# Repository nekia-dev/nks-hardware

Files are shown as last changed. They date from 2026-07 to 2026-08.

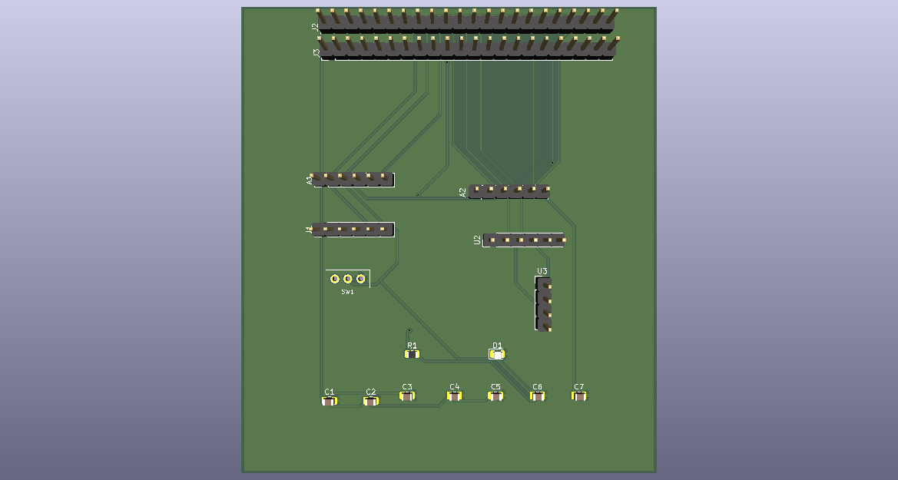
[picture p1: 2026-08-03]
nks-03-08-2026.png

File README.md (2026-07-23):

# NkS — Placa portadora (carrier) · PROYECTO SOMNIA

**Nekia Systems S.L.** · Hardware del monitor de sueño NkS
*"Your Data, Your Device."*

Placa portadora para ESP32-S3 DevKitC-1 N16R8. Diseño "árbol de pascua apagado":
hardware mínimo, el valor está en el software.

---

## Estado

| Etapa | Estado |
|---|---|
| Hardware congelado | ✅ |
| Esquemático + ERC | ✅ 0 errores |
| Layout + DRC | ✅ 0 errores / 0 sin conectar |
| Gerbers | ✅ generados y verificados |
| Fabricación | ⏳ pendiente de pedido |
| Validación física | ⏳ pendiente (ver §Validación) |

---

## Datos de fabricación

| Parámetro | Valor |
|---|---|
| Dimensiones | **80 × 90 mm** (8 × 9 cm) |
| Capas | 2 (F.Cu / B.Cu) |
| Grosor | 1,6 mm (estándar) |
| Contorno | Rectangular |
| Plano de masa | GND en **ambas** caras |
| Pistas | 271 segmentos + 4 vías |
| Taladros | 80 (brocas 0,3 / 1,0 / 1,1 mm) |
| Ancho de pista | 0,2 mm (señal) |
| Componentes | 18 |

> El formato circular queda aplazado: el rectangular abarata el prototipo.

---

## Arquitectura

El ESP32-S3 DevKitC-1 **no va soldado**: se enchufa sobre dos tiras de pines
hembra 1×22 (`J2` = fila J1 del DevKit, `J3` = fila J3). Los sensores y
periféricos son módulos comerciales (breakouts) montados sobre headers.

**Consecuencia:** el fabricante entrega la placa **desnuda**. El montaje
(soldadura de headers y pasivos + enchufar el DevKit) es manual.

---

## Pinout congelado

| Bus | Señal | GPIO | Posición en header |
|---|---|---|---|
| I2S | WS | 11 | J2 pos. 17 |
| I2S | SCK | 12 | J2 pos. 18 |
| I2S | SD | 13 | J2 pos. 19 |
| SPI | MOSI | 15 | J2 pos. 8 |
| SPI | MISO | 16 | J2 pos. 9 |
| SPI | SCLK | 17 | J2 pos. 10 |
| SPI | CS | 18 | J2 pos. 11 |
| I2C | SDA | 8 | J2 pos. 12 |
| I2C | SCL | 9 | J2 pos. 15 |
| — | Botón on/off | 14 | J2 pos. 20 |
| — | LED estado | 21 | J3 pos. 18 |

**Alimentación:** 3V3 en J2 pos. 1–2 · GND en J2 pos. 22 y J3 pos. 1, 21, 22.

**Pines reservados (no usar):** strapping 0/3/45/46 · PSRAM octal (N16R8)
33–37 · USB nativo 19/20.

> El pinout físico J1/J3 procede de la guía oficial de Espressif del
> ESP32-S3-DevKitC-1 v1.1. **Verificar contra la placa real antes de soldar**
> (ver §Validación).

---

## BOM

| Ref | Componente | Interfaz | Notas |
|---|---|---|---|
| J2, J3 | Header 1×22 hembra ×2 | — | Zócalo del DevKit (paso 2,54 mm, filas a 22,86 mm) |
| A1 | INMP441 | I2S | Canal izquierdo — `L/R` → GND |
| A2 | INMP441 | I2S | Canal derecho — `L/R` → 3V3 |
| J1 | Lector microSD | SPI | — |
| U2 | RTC DS3231 + AT24C32 | I2C | 0x68 / 0x57 |
| U3 | SHT30 | I2C | 0x44 — temperatura + humedad |
| SW1 | Pulsador 6 mm | — | On/off, activo-bajo |
| R1 | 1 kΩ (0805) | — | Serie del LED |
| R2 | 10 kΩ (0805) | — | Pull-up del botón |
| D1 | LED (0805) | — | Indicador de estado |
| C1–C6 | 100 nF (0805) | — | Desacoplo + antirrebote |
| C7 | 10 µF (0805) | — | Bulk en el riel 3V3 |

**Aparte (no van en la placa):** ESP32-S3 DevKitC-1 N16R8, tarjeta microSD,
cable USB-C, carcasa.

Todas las huellas proceden de las **librerías estándar de KiCad**; el proyecto
no depende de librerías propias de footprints.

---

## Estructura del repositorio

```
nks.kicad_pro          Proyecto KiCad
nks.kicad_sch          Esquemático
nks.kicad_pcb          Placa (rutada, DRC limpio)
nks.kicad_sym          Biblioteca de símbolos del proyecto
sym-lib-table          Registro de la biblioteca de símbolos
docs/                  Informes de ingeniería
tools/nks-sch-gen/     Generador del esquemático en Rust
```

### Abrir el proyecto

Abrir `nks.kicad_pro` con **KiCad 10.0**. Los cuatro archivos de proyecto y
`sym-lib-table` deben estar en la misma carpeta.

---

## Validación (pendiente al recibir la placa)

El DRC a cero garantiza que la placa **coincide con el esquemático** y es
fabricable. **No** garantiza que el mapeo de pines del DevKit sea correcto.

1. **Continuidad con multímetro** (placa desnuda): comprobar que cada pad de
   los módulos pita con la posición esperada de J2/J3. Prioridad: I2C, I2S, SPI.
2. **Alimentación**: 3V3 y GND presentes en cada módulo antes de montar nada.
3. **Bloque a bloque**: alimentación → I2C (¿responde el RTC en 0x68?) → I2S →
   microSD. No montar todo de golpe.

---

## Decisiones de diseño registradas

- **2× INMP441 en estéreo** por el truco `L/R`: comparten los tres pines I2S sin
  GPIO adicionales. Habilita separar el ronquido propio del de la pareja.
- **SHT30 incorporado** como sensor de ambiente (temp + humedad). Restricción de
  layout: aislarlo térmicamente del DevKit y su regulador.
- **Sin conector USB-C propio**: se usa el USB-C nativo del DevKit.
- **BMP280 descartado**; **BH1750 aplazado**.
- **Plano de GND en ambas caras**: necesario porque D1 es SMD (su pad de masa
  vive solo en F.Cu) y el plano inferior quedó fragmentado por el rutado.

---

*Nekia Systems S.L. — CONFIDENCIAL*

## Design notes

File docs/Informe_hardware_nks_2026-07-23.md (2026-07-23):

# INFORME DE INGENIERÍA — Placa NkS (carrier)
# Nekia Systems S.L. · PROYECTO SOMNIA
# Fecha: 23 de julio de 2026
# Alcance: del pinout congelado a los Gerbers verificados

---

## 1. RESUMEN EJECUTIVO

Se cierra el diseño de la placa portadora del NkS: esquemático con ERC a 0,
layout con DRC a 0 errores y 0 conexiones sin rutar, y Gerbers generados y
verificados capa por capa. Placa de **80 × 90 mm, 2 capas**, con plano de masa
en ambas caras.

En paralelo se reorientó el producto (de dispositivo médico a producto de
consumo con la privacidad como bandera), se añadió el SHT30 como sensor de
ambiente y se pasó a **captura estéreo con dos INMP441**.

Queda pendiente lo único que el DRC no puede validar: **el mapeo de pines del
DevKit contra la placa física**.

---

## 2. DECISIONES DE PRODUCTO Y HARDWARE

### 2.1 Segundo micrófono (estéreo)

Se añade un segundo INMP441 aprovechando el pin `L/R` del integrado: un módulo
con `L/R`→GND (canal izquierdo) y otro con `L/R`→3V3 (canal derecho). Ambos
comparten `WS`/`SCK`/`SD`.

**Coste real:** cero GPIO adicionales y coherencia de fase gratuita (comparten
reloj). El trabajo se traslada al software: I2S a 2 canales, formato `.nka` con
dos canales (dobla almacenamiento) y colocación intencional de A1/A2 en el
layout (define el *baseline* estéreo).

**Descartado:** matrices de 4+ micrófonos. El INMP441 no soporta TDM
multicanal; un array mayor exigiría otro sensor y otro diseño.

### 2.2 SHT30 (temperatura + humedad)

Entra al bus I2C existente (0x44) sin GPIO nuevos. Se acepta como **feature de
producto** ("ambiente del dormitorio"), no como dato suelto: el DS3231 ya ofrece
temperatura aproximada, pero mide su propio die y no sirve como medida ambiental.

**Restricción de layout:** aislar del DevKit y su regulador; de lo contrario
reporta temperatura alta y humedad baja.

### 2.3 Sin conector USB-C propio

El DevKitC-1 ya expone el USB-C nativo del ESP32-S3 (vía para el futuro USB Mass
Storage). Se elimina el bloque de conector independiente.

### 2.4 Contorno rectangular

Se aplaza el formato circular: el rectangular abarata el prototipo y el contorno
no aporta valor hasta validar la electrónica.

---

## 3. FLUJO DE TRABAJO ADOPTADO

El esquemático se generó **programáticamente con una herramienta propia en
Rust** (`tools/nks-sch-gen`), que emite `.kicad_sch`, `.kicad_sym` y
`sym-lib-table`. El usuario ejecuta, revisa y ajusta en KiCad 10.

**Justificación:** reproducibilidad y control de versiones del esquemático; se
evita Python por decisión de toolchain del proyecto.

**Limitación asumida:** un esquemático generado queda correcto en conectividad
(net labels) pero no en estética. La reorganización visual, si se quiere, es
manual.

---

## 4. INCIDENCIAS RESUELTAS (y su causa raíz)

### 4.1 Formato `.kicad_sch` rechazado por KiCad

**Causa:** los sub-símbolos anidados se emitían con el prefijo de biblioteca
(`nks:R1_0_1`). KiCad exige el nombre sin prefijo (`R1_0_1`).

### 4.2 Referencias marcadas como "sin anotar"

**Causa:** las instancias apuntaban a la ruta `/` en lugar de a la UUID de la
hoja raíz. Corregido en el generador.

**Relacionado:** referencias tipo `J1H`/`J3H` son inválidas en KiCad (deben
terminar en número). Renombradas a `J2`/`J3`.

### 4.3 "No se ha encontrado la huella 'nks:ESP32-S3-DevKitC-1'"

**Causa:** se creó un footprint a medida en una biblioteca de proyecto
(`nks.pretty` + `fp-lib-table`) que KiCad no cargaba de forma fiable.

**Solución adoptada:** eliminar la biblioteca propia y representar el DevKit
como **dos conectores 1×22 estándar** (`J2`, `J3`) con huellas de la librería
oficial. Cada pin lleva el número de su **posición física** en los headers J1/J3
del DevKitC-1 v1.1.

> **Regla aprendida:** evitar bibliotecas de footprints propias mientras existan
> huellas estándar equivalentes.

### 4.4 90 infracciones de margen en el layout

**Causa:** se había colocado un plano de +3V3 en `F.Cu`, la misma cara por la
que se rutaban las señales. Plano y pistas competían por el mismo espacio.

**Solución:** eliminar el plano de 3V3; el 3V3 pasa a pistas. `F.Cu` queda para
señales.

> **Regla aprendida:** un plano ocupa la cara entera; no se comparte cara entre
> plano y rutado manual denso.

### 4.5 Rutado manual bloqueado

Con las señales en una sola cara, el router interactivo dejaba de encontrar
camino (SD_CS, SD_MISO, SD_SCLK, LED_STAT, +3V3). No era un error de diseño:
falta de espacio.

**Solución:** autorouter externo (**Freerouting**), que usa ambas caras y coloca
vías. Resultado: 42 nets sin rutar → **0**, en 1,27 s.

**Nota operativa:** el GUI de Freerouting v2.2.4 falla
(`parent_iconified ... null`). Se usó en modo terminal:

```
./freerouting -de nks.dsn -do nks.ses
```

### 4.6 KiCad se cerraba al importar el `.ses`

**Causa:** el footprint del pulsador tiene pads con número duplicado (`1`,`1`,
`2`,`2`). Freerouting los desambigua como `SW1-1@1`; el importador Specctra de
KiCad no interpreta esa sintaxis y aborta con *"No se ha encontrado la
referencia 'SW1'"*.

**Solución adoptada:** convertir el rutado del `.ses` (271 segmentos + 4 vías) e
insertarlo directamente en el `.kicad_pcb`, evitando el importador. Transformada
de coordenadas verificada contra tres componentes (unidades/10000 = mm, Y
invertida).

### 4.7 Pads de GND sin conectar al plano

Persistían pads de masa sueltos (A1, A2, U2, U3, D1) pese a existir plano en
`B.Cu`.

**Causa raíz:** `D1` es **SMD** — su pad de masa vive solo en `F.Cu` y no puede
alcanzar un plano situado en la cara opuesta. Además, el plano inferior había
quedado **fragmentado** por las pistas que el autorouter trazó en `B.Cu`,
aislando pads pasantes en islas.

**Solución:** añadir una **segunda zona de GND en `F.Cu`**. Con masa en ambas
caras, todo pad —SMD o pasante— encuentra cobre de masa en su propia cara.
Resultado: `unconnected_items` → **0**.

> **Regla aprendida:** con componentes SMD, el plano de masa debe existir en la
> cara donde viven sus pads.

### 4.8 Avisos `starved_thermal`

Tres pads (A1, A2, U3) conectaban al plano con 1 radio de alivio térmico frente
a los 2 exigidos por defecto.

**Solución:** *Ajustes de la placa → Requerimientos → Cantidad mínima de radios
de alivio térmico* = **1**. Los pads estaban conectados; era una exigencia
cosmética.

### 4.9 Incidencia: borrado global excesivo

Un `Editar → Borrado global` para limpiar pistas de GND eliminó buena parte del
rutado (35 nets sin rutar). Se recuperó desde una copia previa del archivo
rutado. **Precaución:** no usar borrado global sin copia de seguridad previa.

---

## 5. VERIFICACIÓN DE GERBERS

Pack analizado archivo por archivo:

| Capa | Estado |
|---|---|
| `F_Cu` | ✅ 4727 trazos |
| `B_Cu` | ✅ 4056 trazos |
| `F_Mask` / `B_Mask` | ✅ |
| `F_Silkscreen` / `B_Silkscreen` | ✅ |
| `Edge_Cuts` | ✅ rectángulo cerrado 80 × 90 mm |
| `PTH.drl` | ✅ 80 agujeros (brocas 0,3 / 1,0 / 1,1 mm) |
| `.gbrjob` | ✅ todas las capas declaradas |

**Recuento cruzado de taladros:** 44 (J2+J3) + 18 (A1, A2, J1) + 10 (U2, U3) +
4 (SW1) + 4 (vías) = **80**. Coincide.

**Conclusión:** pack completo y coherente, apto para fabricación.

---

## 6. PENDIENTES

### Crítico (antes de soldar)
1. **Verificar el mapeo de pines del DevKit con multímetro.** Es el único
   eslabón no validado: el footprint se construyó desde la documentación
   oficial, y ni el DRC ni los Gerbers pueden detectar un error ahí.

### Fabricación
2. Pedir la placa (JLCPCB / PCBWay) y trasladar el **precio real** al modelo de
   costes `NkS_costes.xlsx` (celda de fabricación de placa).
3. Cotizar componentes y carcasa — entregable de costes: **última semana de
   agosto de 2026**.

### Hardware por confirmar
4. **Pull-ups de I2C**: se asumen presentes en los breakouts de RTC y SHT30.
   Verificar; si ninguno los trae, añadir un par de 4,7 kΩ.
5. **Orden pin↔pad** de los headers de módulo frente a los breakouts reales.

### Mejoras aplazadas
6. Ensanchar las pistas de `+3V3` (actualmente 0,2 mm por defecto del
   autorouter). Suficiente para el consumo actual, mejorable.
7. Formato circular y reducción de tamaño (hay margen sobrado en 80 × 90 mm).
8. Modelos 3D de los módulos, para validar volumen frente a la futura carcasa.

### Software (rama aparte)
9. Refactor a `single-idf`: partir del firmware actual y retirar lo que ya no
   monta la placa (BH1750, BMP280, OLED), pasar el I2S a 2 canales y versionar
   el formato `.nka` para audio estéreo + temperatura/humedad.

---

## 7. NOTAS DE MÉTODO

- **El DRC valida coherencia, no corrección.** Comprueba que la placa cumple las
  reglas y coincide con el esquemático; no que el esquemático sea correcto.
- **Distinguir conexión lógica de conexión física.** Las líneas finas
  (*ratsnest*) expresan intención; solo el cobre conecta. El contador "sin
  rutar" es el indicador fiable, no el DRC filtrado por severidad.
- **En una placa de 2 caras:** masa por plano, señales por pista. Los pads de
  masa bajan al plano con vías; no se rutea GND con pistas.
- **Copia de seguridad antes de operaciones masivas** (borrado global, importes
  de sesión, cambios de zona).

---

*Nekia Systems S.L. — CONFIDENCIAL*
*"Your Data, Your Device." 🌙*

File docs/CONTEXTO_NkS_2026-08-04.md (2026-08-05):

# INFORME DE INGENIERÍA / CONTEXTO — NkS
# Nekia Systems S.L. · Ivan (nekia-dev)
# Fecha de cierre: 4 de agosto de 2026
# Alcance: generador Rust del esquematico recreado + refactorizado (Capa 1: SW1->SPDT,
#          quitar R2). Decisiones: SHT30 se mantiene, distribucion fisica, estrategia.
# Destino: sesion siguiente (decidir sincronizacion sch<->pcb; Capas 2-3: ENABLE, TPS22918)

---

## 0. CÓMO TRABAJAMOS
- Español, "nosotros", instrucciones cortas con el porque. Medir antes de teorizar, un
  cambio verificable a la vez, copia de seguridad antes de operaciones de riesgo.
- **NUEVO ENFOQUE DE TRABAJO (definido hoy, valido a futuro):** el **generador en Rust
  (`nks-sch-gen`) es la FUENTE DE VERDAD del esquematico**. Los cambios de diseño se hacen
  en el generador (main.rs), se regenera el `.kicad_sch`, y el LAYOUT (PCB) lo ajusta Ivan
  a mano en KiCad 10. El agente ayuda a escribir/modificar el codigo Rust; Ivan compila y
  ejecuta en su maquina (`ltc`). "Rust si, Python no" (NO usar kiutils; el generador es Rust).

---

## 1. DECISIÓN ESTRATÉGICA DE FONDO (importante)
- **Reducir la dependencia del asistente.** El conocimiento del proyecto debe vivir en
  DOCUMENTACION y PROCEDIMIENTOS reproducibles, no en el asistente (que NO persiste entre
  sesiones; cada sesion es una instancia nueva que solo sabe lo que se le trae en contexto)
  ni solo en Ivan (una sola persona). Riesgo identificado por Ivan: "si no estas, el negocio
  es una ruina".
- **Plan:** cerrar la placa -> fase de documentacion/procedimientos del sistema NkS.
  Objetivo: negocio transferible, defendible ante inversor, y base para la linea de formacion
  (electronica embebida + Rust). La documentacion debe hacer a Ivan AUTONOMO, no perpetuar
  la dependencia.
- **SUBVENCION APROBADA: 7.500 EUR — pago octubre 2026.** Condiciona calendario (alta de
  autonomo, forma juridica societario vs individual, compras, ROI/IVA).

---

## 2. HITO DE HOY — generador Rust recreado + Capa 1 refactorizada

### Contexto: DOS lineas de trabajo desincronizadas (detectado y en via de resolucion)
- Una instancia ANTERIOR construyo un generador de esquematico en Rust (`nks-sch-gen`) que
  produce el `.kicad_sch` por codigo. Pero ese generador reflejaba el diseño VIEJO (SW1
  pulsador, R2 presente) — NO incorporaba el trabajo hecho a mano en las sesiones recientes.
- Esta sesion (y las previas): se edito el `.kicad_pcb` a MANO (SW1->SPDT, R2 borrado,
  rutado, DRC 0). -> Las dos lineas divergian. Hoy se empieza a consolidar en el generador.

### Recreado el proyecto Cargo
- Ubicacion: **`~/Documentos/NEKIA-SYSTEM/nks-hardware/tools/nks-sch-gen/`** (dentro del repo,
  versionado con el diseño). Ficheros: `src/main.rs` (declaracion de bloques) + `src/kicad.rs`
  (motor que escribe el `.kicad_sch`, 485 lineas, solo std). `cargo build` OK.
- NOTA: el proyecto original no estaba en la maquina de Ivan (lo construyo la otra instancia
  en su entorno); Ivan solo tenia los ficheros sueltos en `refactoriza/`. Se recreo el Cargo.
- Aviso rust-analyzer "failed to find any projects in nks-hardware": INOFENSIVO — el editor
  busca Cargo.toml en la raiz del repo, pero esta en tools/nks-sch-gen/. Solucion opcional:
  `.vscode/settings.json` con `"rust-analyzer.linkedProjects":["tools/nks-sch-gen/Cargo.toml"]`.

### Capa 1 aplicada en main.rs (SINCRONIZA generador con la realidad) — VERIFICADA
1. Constante footprint: `const SW_SPDT: &str = "nks:SS12D00";` (antes BTN6MM del pulsador).
2. `R2` (pull-up 10k) ELIMINADO.
3. `SW1` -> SPDT 3 pines: `pin 2 (comun)->BTN`, `pin 1->+3V3`, `pin 3->GND`. Footprint
   `nks:SS12D00`. Value "SW_SPDT".
- `cargo run --release` OK -> genero `nks.kicad_sch` (52409 bytes) en tools/nks-sch-gen/
  (ruta relativa; NO piso el .kicad_sch de la raiz — a proposito).
- **Verificacion (grep sobre el generado):** R2=0 ✓; SS12D00 presente ✓; **17 componentes**
  (antes 18) ✓; SW1 con nets +3V3/BTN/GND (uno de cada) ✓. Capa 1 CERRADA.

---

## 3. DECISIÓN PENDIENTE CLAVE — sincronizacion sch<->pcb (NO resuelta, para mañana)
El `.kicad_sch` generado esta limpio, PERO no se puede volcar sin mas al proyecto:
- El PCB de la raiz ya tiene el LAYOUT trabajado a mano (rutado, DRC 0), con los UUID de
  componentes del esquematico VIEJO.
- El generador crea UUID NUEVOS -> si se reemplaza el .sch y se hace *Update PCB from
  Schematic*, KiCad veria todos los componentes como nuevos -> borraria el layout/rutado
  existente. Riesgo de perder el trabajo manual del PCB.

**Opciones (decidir con mente lucida):**
- **A) El generador manda -> rehacer el layout desde cero.** Coherente con el nuevo enfoque.
  Como la reorganizacion que viene (USB-C detras, panel frontal, +TPS22918/ENABLE) va a
  rehacer el layout DE TODOS MODOS, la perdida del rutado actual es asumible. RECOMENDADA.
- **B) Mantener el PCB actual a mano; el generador queda de referencia.** Conserva el rutado
  pero perpetua la divergencia.

Si se va por A: meter tambien Capas 2-3 (ENABLE, TPS22918) en el generador ANTES de
reconstruir el layout UNA sola vez (no reconstruir dos veces).

---

## 4. REFACTORIZACIÓN PENDIENTE DEL GENERADOR (Capas 2-3)
- **Capa 2:** añadir `ENABLE` -> sacar `GPIO4` (J2 pos.4, libre, RTC-capable, validado) a un
  net ENABLE en el header J2.
- **Capa 3:** añadir `TPS22918` (load switch, parte +3V3 en +3V3_IN/+3V3_SW, EN=ENABLE) +
  divisor VBUS->ADC (5Vin en J2 pos.21; ADC libre GPIO5/6/7) + posible bulk mayor.
  Requiere definir pines del TPS22918 y valores del divisor.
- Nota: C6 (100n) sigue conectado a BTN/GND (antirrebote) — inofensivo con el SPDT, se deja.

---

## 5. DECISIONES DE PRODUCTO DE HOY
- **SHT30 (U3): SE MANTIENE.** Se valoro quitarlo por coste (ajustados), pero: (a) es un
  diferenciador de producto (ambiente del dormitorio = dato clinico/venta); (b) ya esta
  integrado; (c) ahorro modesto (~2-4 EUR). Opcion elegante disponible si hiciera falta:
  dejar el socket y hacer el MODULO opcional (el firmware detecta si responde en I2C 0x44).
  Por ahora se queda como esta.
- **Distribucion fisica de la placa (requisito de LAYOUT, no de esquematico):**
  - Borde FRONTAL: **LED (D1) + interruptor SS12D00G (SW1)** — interaccion del usuario.
  - Borde POSTERIOR: **USB-C del DevKit ("cola")** — alimentacion oculta, no cruza por
    delante. Implica ORIENTAR el DevKit sobre J2/J3 para que su USB-C nativo caiga detras.
  - Esto NO afecta al generador (el esquematico no sabe de frontal/posterior); se aplica al
    colocar componentes en el PCB.

---

## 6. ESTADO GLOBAL
- **Firmware `single-idf`:** terminado para la fase (soft power latch integrado y validado,
  commiteado). USB Mass Storage (ST-023) imprescindible (habilita "caja con USB-C").
- **Placa:** interruptor cerrado en el PCB actual (DRC 0, commiteado). Generador Rust
  sincronizado (Capa 1). Pendiente: decidir estrategia sch<->pcb + Capas 2-3 + reorganizar
  layout (USB-C detras) + regenerar Gerbers.
- **Costes:** curva PCB real (Saving: ~1.95/ud a 100u); BOM en CSV entregado. Los dos
  presupuestos base los construye Ivan (entregable ultima semana agosto, accionista).
- **Carcasa:** referencia visual validada (box router, rejilla, patas, panel USB-C detras +
  LED/switch delante). Cotas reales ~9x9.5cm; alto por confirmar con modelo 3D. Punto abierto:
  mecanica del actuador del switch (SS12D00G sin pestañas -> carro en carcasa o SS12F15).
- **Alimentacion:** por USB-C (regulador del DevKit -> 3V3). Divisor VBUS vigila los 5V.
  Pendiente decidir si la caja incluye cargador USB (recomendado, ~3-5 EUR).
- **Prioritario no-firmware:** rotar credenciales del historial git (`9991c9e`, `d751b87`).
  SIGUE PENDIENTE.

---

## 7. TEMAS ABIERTOS
- Estrategia de sincronizacion sch<->pcb (A vs B) — PRIMERA decision de mañana.
- Mecanica del actuador del switch — con la carcasa.
- Modelos 3D de modulos -> alto real de carcasa.
- Mapeo pines DevKit<->placa sin validar con multimetro (critico antes de soldar).
- Forma juridica + ROI/IVA — pendiente de la subvencion (oct 2026).
- Documentar donde vive y como se ejecuta el generador (hecho parcialmente en este informe:
  tools/nks-sch-gen/, `cargo run --release` genera el .kicad_sch en ese directorio).

---

## 8. SIGUIENTE SESIÓN — arranque
1. Decidir estrategia sch<->pcb (recomendada A: generador manda, rehacer layout).
2. Si A: meter Capa 2 (ENABLE) y Capa 3 (TPS22918 + divisor) en el generador.
3. Regenerar, validar (ERC en KiCad 10), y reconstruir el layout UNA vez con la
   distribucion nueva (USB-C detras, LED+switch delante).
4. Regenerar Gerbers -> precio PCB final.

---

*Nekia Systems S.L. — CONFIDENCIAL · "Your Data, Your Device." 🌙*

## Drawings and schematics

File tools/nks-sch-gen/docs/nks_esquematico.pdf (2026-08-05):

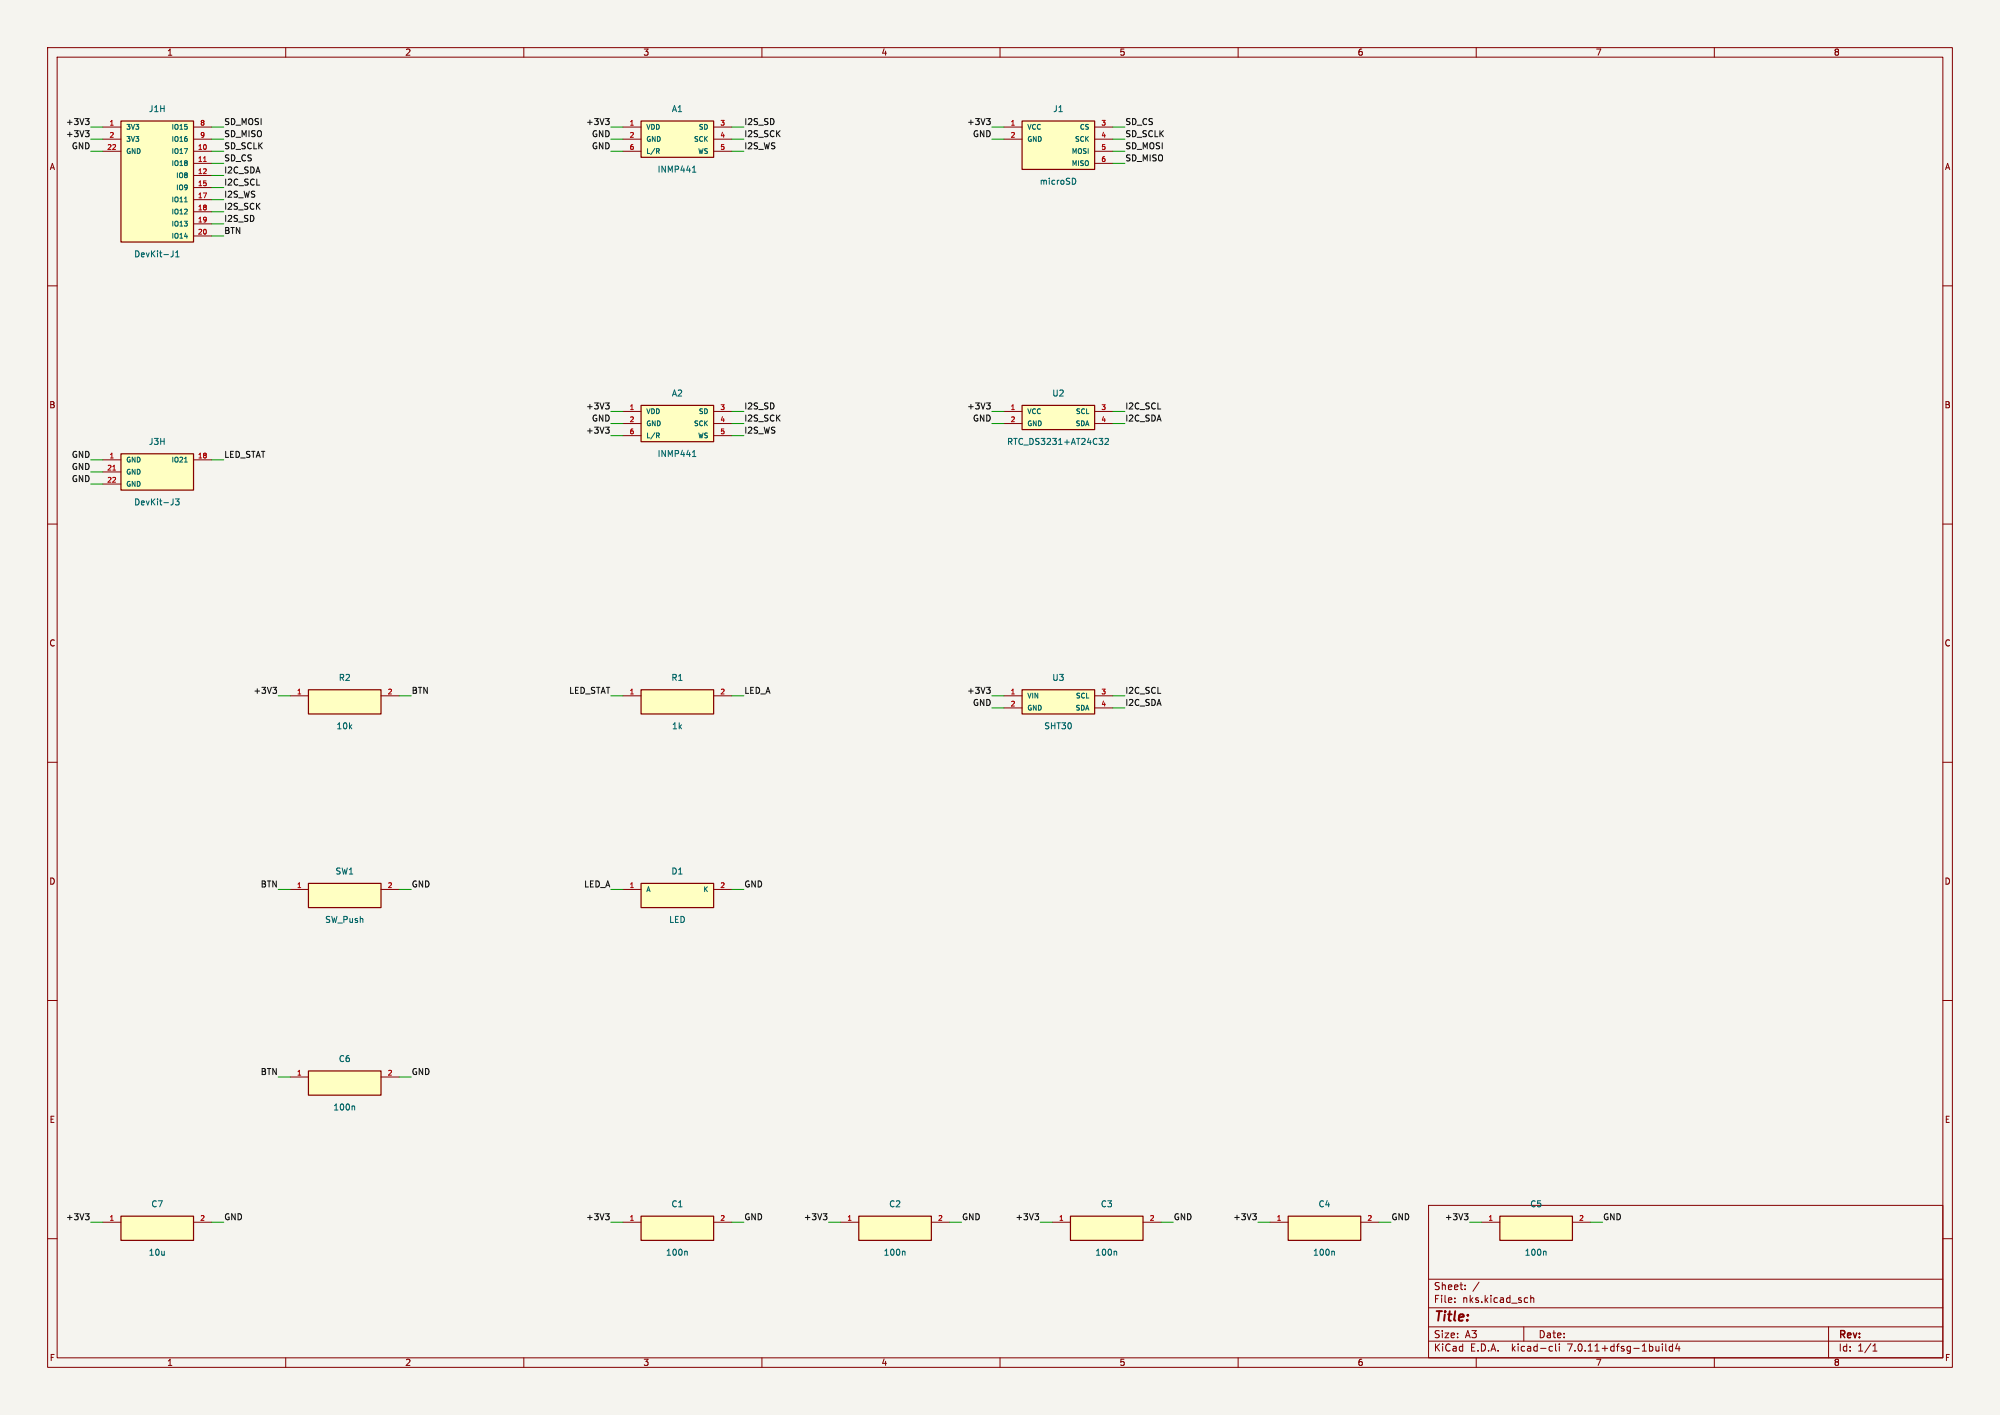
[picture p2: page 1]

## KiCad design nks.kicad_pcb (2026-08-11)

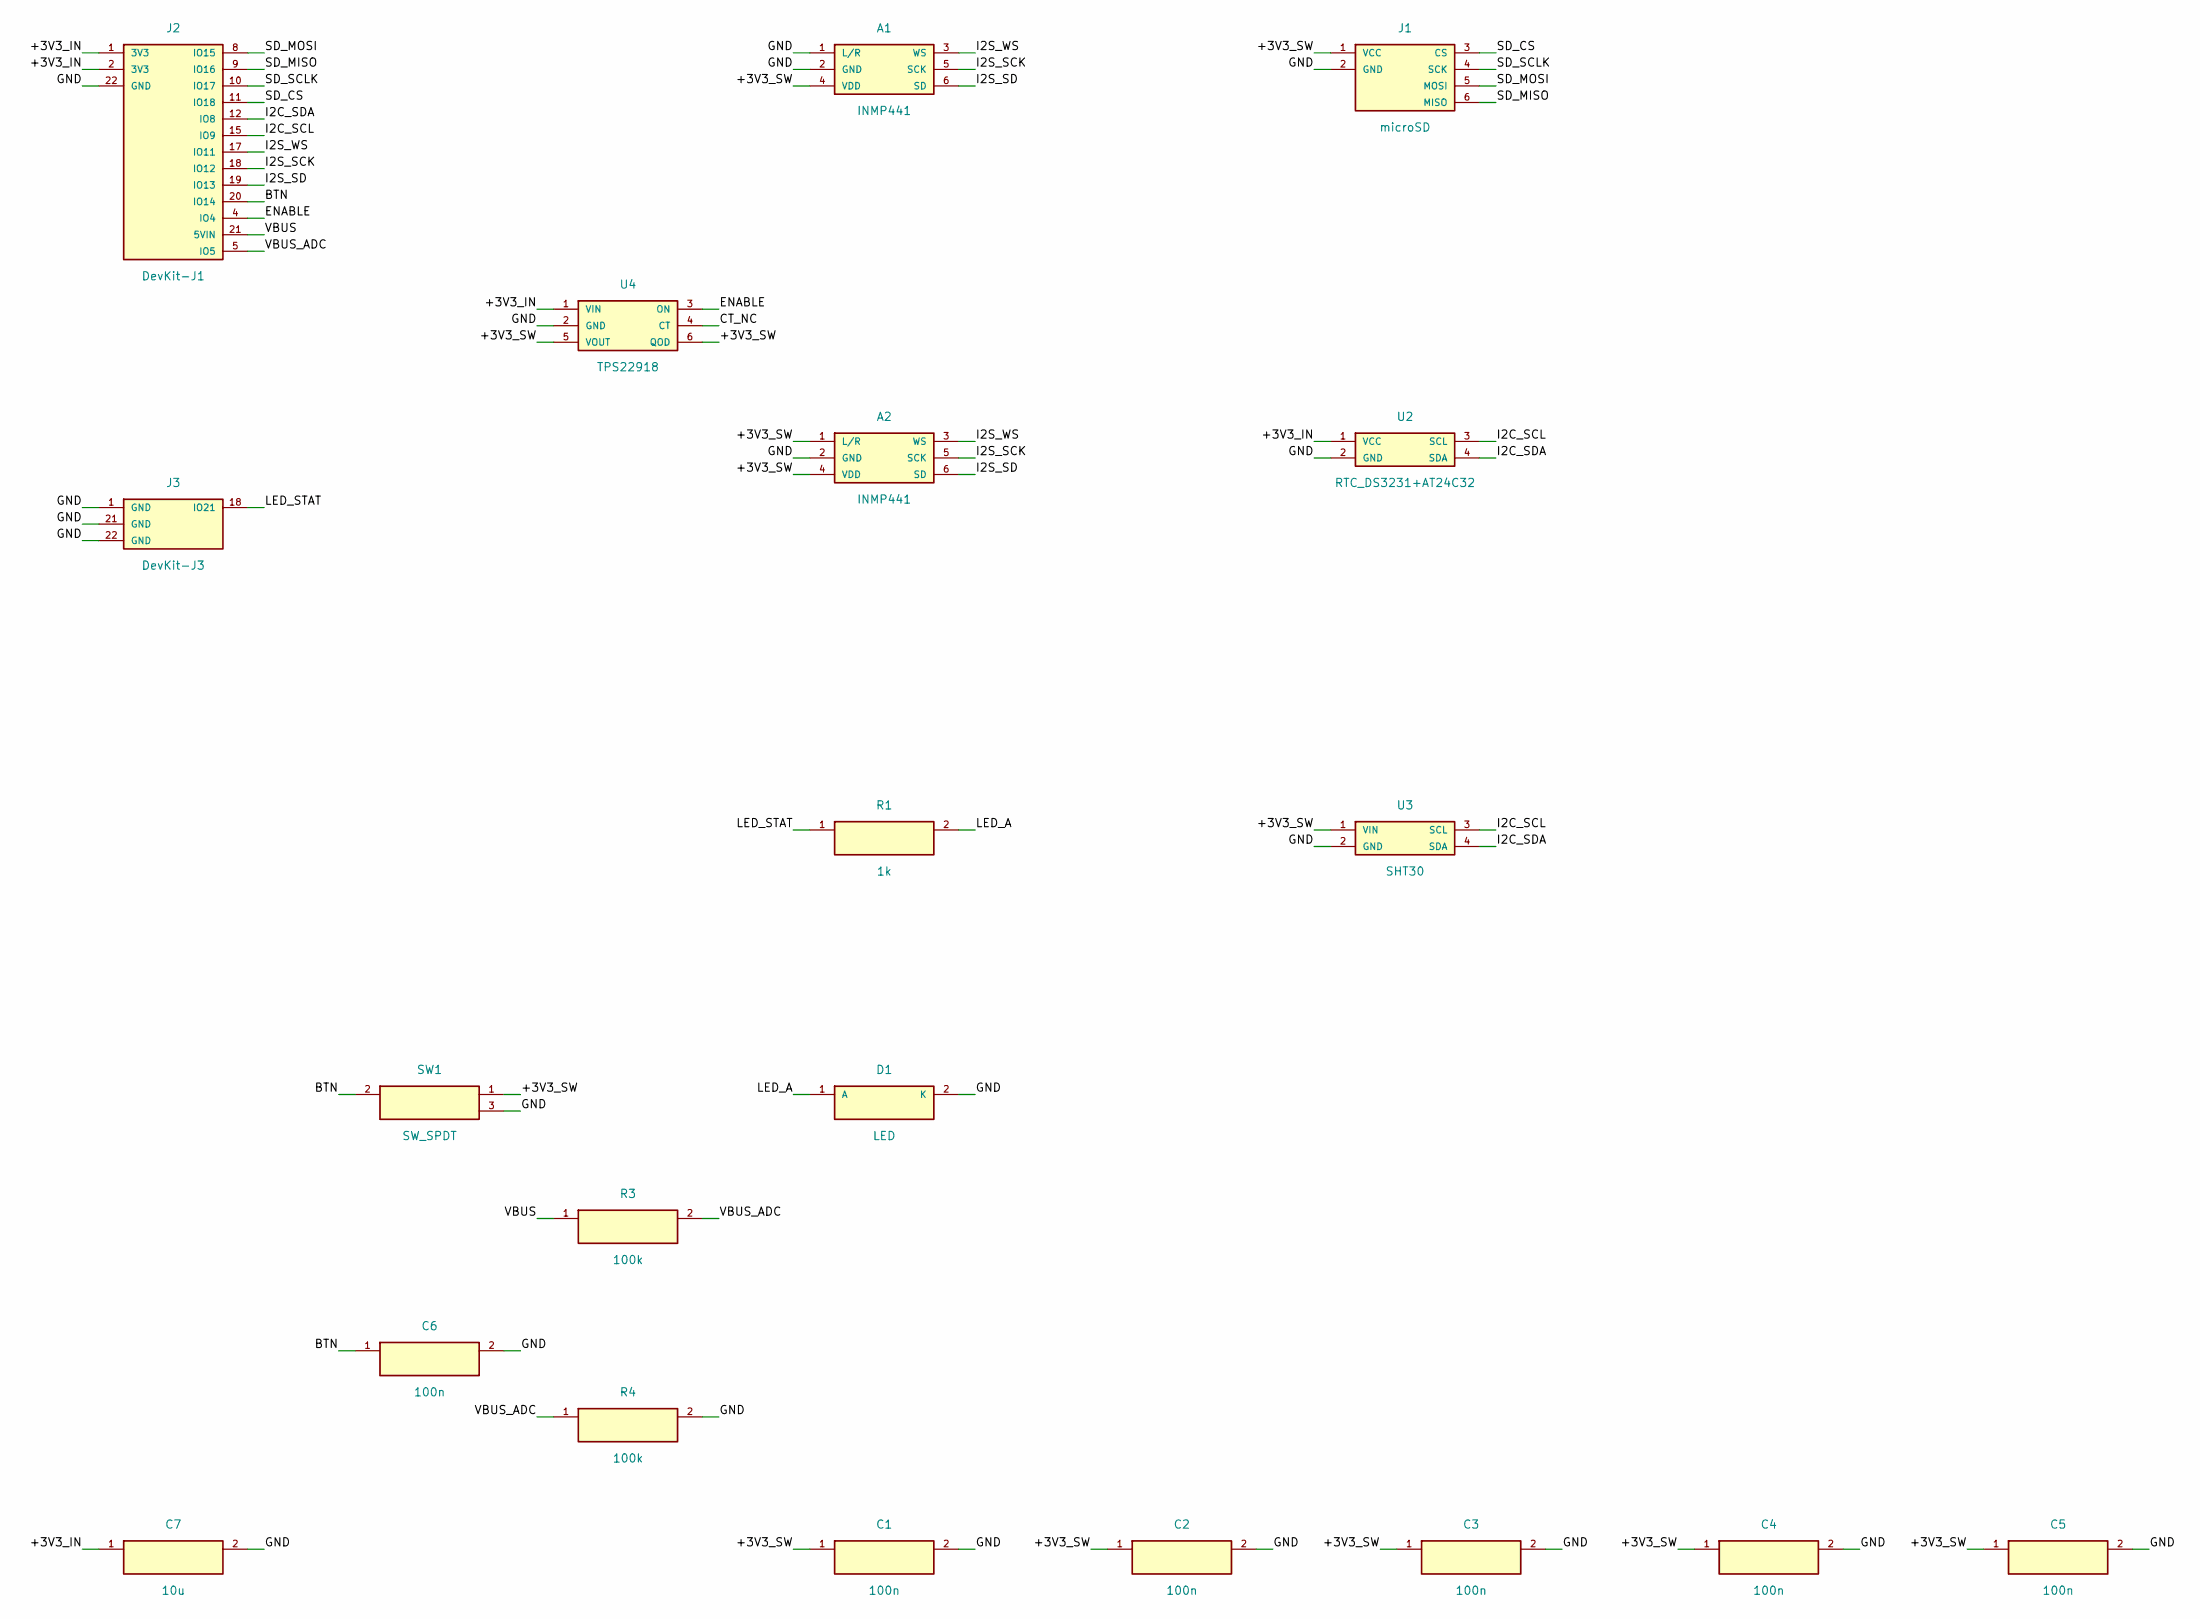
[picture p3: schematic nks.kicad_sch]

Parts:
A1, A2: INMP441; PinHeader_2x03_P2.54mm_Vertical
C1, C2, C3, C4, C5, C6: 100n; C_0805_2012Metric
C7: 10u; C_0805_2012Metric
D1: LED; LED_0805_2012Metric
J1: microSD; PinHeader_1x06_P2.54mm_Vertical
J2: DevKit-J1; PinHeader_1x22_P2.54mm_Vertical
J3: DevKit-J3; PinHeader_1x22_P2.54mm_Vertical
R1: 1k; R_0805_2012Metric
R3, R4: 100k; R_0805_2012Metric
SW1: SW_SPDT; SS12D00
U2: RTC_DS3231+AT24C32; PinHeader_1x06_P2.54mm_Vertical
U3: SHT30; PinHeader_1x04_P2.54mm_Vertical
U4: TPS22918; SOT-23-6

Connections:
/+3V3_IN: C7.1, J2.1 (3V3), J2.2 (3V3), U2.1 (VCC), U4.1 (VIN)
/+3V3_SW: A1.4 (VDD), A2.1 (L/R), A2.4 (VDD), C1.1, C2.1, C3.1, C4.1, C5.1, J1.1 (VCC), SW1.1, U3.1 (VIN), U4.5 (VOUT), U4.6 (QOD)
/BTN: C6.1, J2.20 (IO14), SW1.2
/CT_NC: U4.4 (CT)
/ENABLE: J2.4 (IO4), U4.3 (ON)
/GND: A1.1 (L/R), A1.2 (GND), A2.2 (GND), C1.2, C2.2, C3.2, C4.2, C5.2, C6.2, C7.2, D1.2 (K), J1.2 (GND), J2.22 (GND), J3.1 (GND), J3.21 (GND), J3.22 (GND), R4.2, SW1.3, U2.2 (GND), U3.2 (GND), U4.2 (GND)
/I2C_SCL: J2.15 (IO9), U2.3 (SCL), U3.3 (SCL)
/I2C_SDA: J2.12 (IO8), U2.4 (SDA), U3.4 (SDA)
/I2S_SCK: A1.5 (SCK), A2.5 (SCK), J2.18 (IO12)
/I2S_SD: A1.6 (SD), A2.6 (SD), J2.19 (IO13)
/I2S_WS: A1.3 (WS), A2.3 (WS), J2.17 (IO11)
/LED_A: D1.1 (A), R1.2
/LED_STAT: J3.18 (IO21), R1.1
/SD_CS: J1.3 (CS), J2.11 (IO18)
/SD_MISO: J1.6 (MISO), J2.9 (IO16)
/SD_MOSI: J1.5 (MOSI), J2.8 (IO15)
/SD_SCLK: J1.4 (SCK), J2.10 (IO17)
/VBUS: J2.21 (5VIN), R3.1
/VBUS_ADC: J2.5 (IO5), R3.2, R4.1

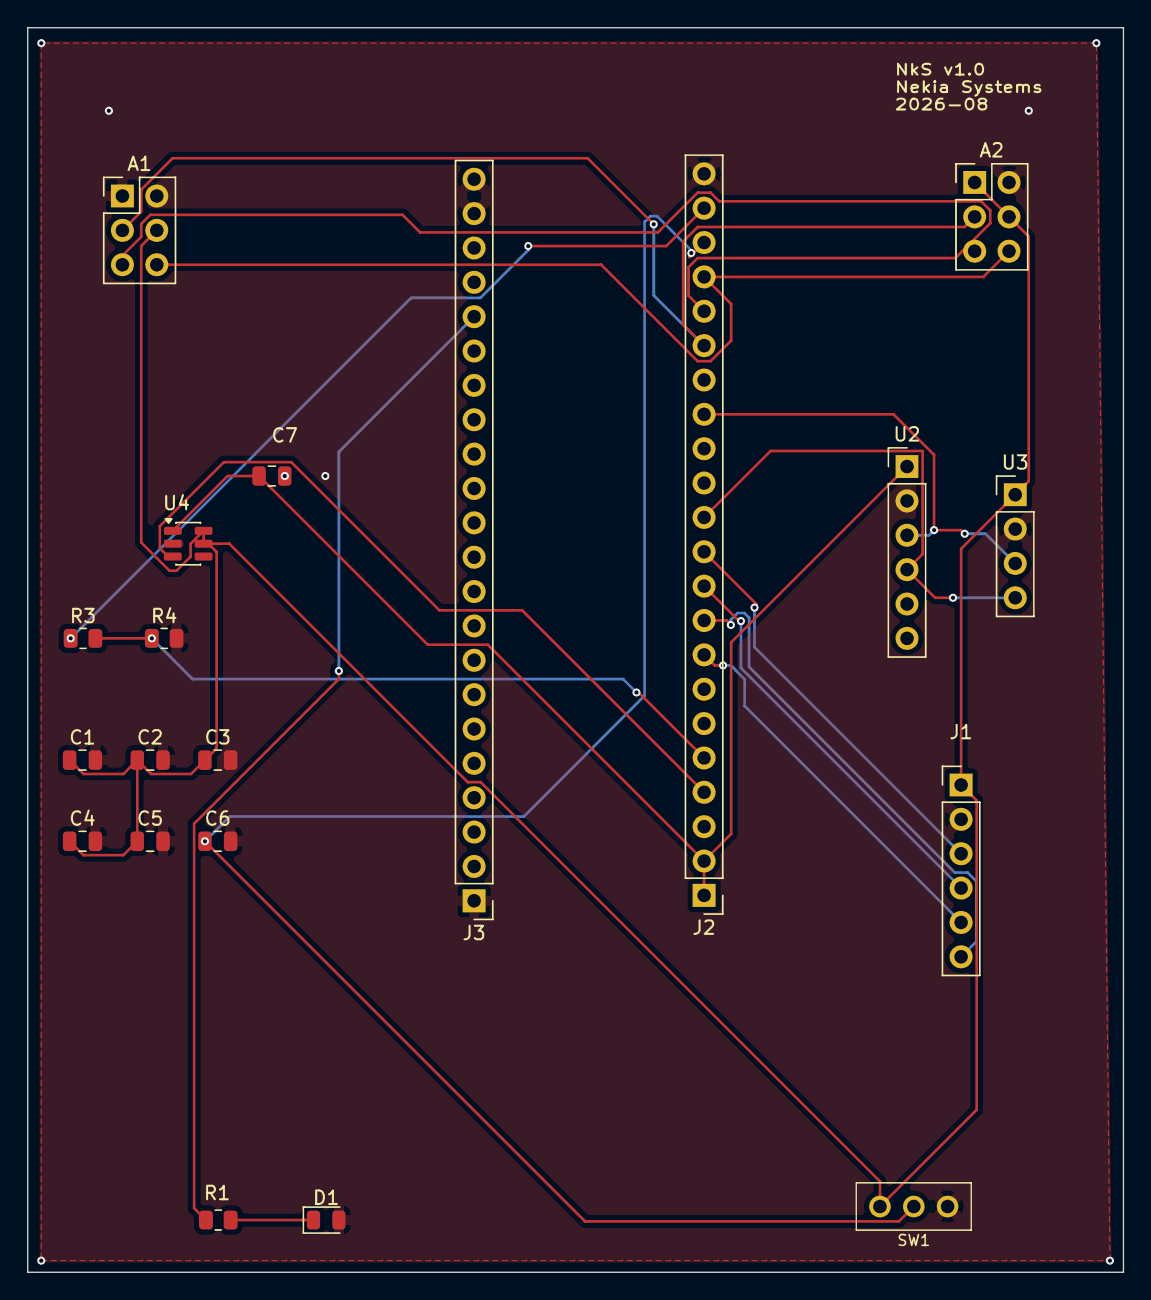
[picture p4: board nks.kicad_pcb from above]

Board: 2 copper layers, 81.0 x 92.0 mm, 20 parts (0 on the bottom side), 18 nets.

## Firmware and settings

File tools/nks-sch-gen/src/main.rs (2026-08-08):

mod kicad;
use kicad::{Component, Elec, Pin, Schematic, Side};

fn p_in(num: &str, name: &str, net: &str) -> Pin { Pin::new(num, name, Side::Left, Elec::PowerIn, net) }
fn p_out(num: &str, name: &str, net: &str) -> Pin { Pin::new(num, name, Side::Left, Elec::PowerOut, net) }
fn sig(num: &str, name: &str, net: &str) -> Pin { Pin::new(num, name, Side::Right, Elec::Passive, net) }
fn gpio(num: &str, name: &str, net: &str) -> Pin { Pin::new(num, name, Side::Right, Elec::Bidi, net) }
fn pas_l(num: &str, name: &str, net: &str) -> Pin { Pin::new(num, name, Side::Left, Elec::Passive, net) }
fn pas_r(num: &str, name: &str, net: &str) -> Pin { Pin::new(num, name, Side::Right, Elec::Passive, net) }

const HDR6: &str = "Connector_PinHeader_2.54mm:PinHeader_1x06_P2.54mm_Vertical";
const HDR4: &str = "Connector_PinHeader_2.54mm:PinHeader_1x04_P2.54mm_Vertical";
const HDR22: &str = "Connector_PinHeader_2.54mm:PinHeader_1x22_P2.54mm_Vertical";
const HDR2X3: &str = "Connector_PinHeader_2.54mm:PinHeader_2x03_P2.54mm_Vertical";
const R0805: &str = "Resistor_SMD:R_0805_2012Metric";
const C0805: &str = "Capacitor_SMD:C_0805_2012Metric";
const LED0805: &str = "LED_SMD:LED_0805_2012Metric";
const SW_SPDT: &str = "nks:SS12D00";
const SOT236: &str = "Package_TO_SOT_SMD:SOT-23-6";

fn main() {
    let mut sch = Schematic::new("NkS - SOMNIA carrier");

    // DevKit = two stock 1x22 female headers it plugs into. Pin NUMBER = physical
    // position on the official J1/J3 header (DevKitC-1 v1.1). One driver per rail
    // (3V3 + GND power_out, rest passive) to avoid multiple-power-output ERC errors.
    // J1 header row:
    sch.add(Component::new("J2", "DevKit-J1", HDR22, 20.0, 20.0)
        .pin(p_out("1", "3V3", "+3V3_IN")).pin(pas_l("2", "3V3", "+3V3_IN")).pin(p_out("22", "GND", "GND"))
        .pin(gpio("8", "IO15", "SD_MOSI")).pin(gpio("9", "IO16", "SD_MISO"))
        .pin(gpio("10", "IO17", "SD_SCLK")).pin(gpio("11", "IO18", "SD_CS"))
        .pin(gpio("12", "IO8", "I2C_SDA")).pin(gpio("15", "IO9", "I2C_SCL"))
        .pin(gpio("17", "IO11", "I2S_WS")).pin(gpio("18", "IO12", "I2S_SCK"))
        .pin(gpio("19", "IO13", "I2S_SD")).pin(gpio("20", "IO14", "BTN"))
        .pin(gpio("4", "IO4", "ENABLE"))
        .pin(gpio("21", "5VIN", "VBUS"))
        .pin(gpio("5", "IO5", "VBUS_ADC")));    // J3 header row:
    
    sch.add(Component::new("J3", "DevKit-J3", HDR22, 20.0, 90.0)
        .pin(pas_l("1", "GND", "GND")).pin(pas_l("21", "GND", "GND")).pin(pas_l("22", "GND", "GND"))
        .pin(gpio("18", "IO21", "LED_STAT")));

    // Load switch: parte +3V3_IN -> +3V3_SW, gobernado por ENABLE (GPIO4).
    sch.add(Component::new("U4", "TPS22918", SOT236, 90.0, 60.0)
        .pin(p_in("1", "VIN", "+3V3_IN")).pin(p_in("2", "GND", "GND"))
        .pin(sig("3", "ON", "ENABLE")).pin(sig("4", "CT", "CT_NC"))
        .pin(p_out("5", "VOUT", "+3V3_SW")).pin(sig("6", "QOD", "+3V3_SW")));

    sch.add(Component::new("A1", "INMP441", HDR2X3, 130.0, 20.0)
        .pin(pas_l("1", "L/R", "GND")).pin(p_in("2", "GND", "GND"))
        .pin(sig("3", "WS", "I2S_WS")).pin(p_in("4", "VDD", "+3V3_SW"))
        .pin(sig("5", "SCK", "I2S_SCK")).pin(sig("6", "SD", "I2S_SD")));
    
    sch.add(Component::new("A2", "INMP441", HDR2X3, 130.0, 80.0)
        .pin(pas_l("1", "L/R", "+3V3_SW")).pin(p_in("2", "GND", "GND"))
        .pin(sig("3", "WS", "I2S_WS")).pin(p_in("4", "VDD", "+3V3_SW"))
        .pin(sig("5", "SCK", "I2S_SCK")).pin(sig("6", "SD", "I2S_SD")));


    sch.add(Component::new("J1", "microSD", HDR6, 210.0, 20.0)
        .pin(p_in("1", "VCC", "+3V3_SW")).pin(p_in("2", "GND", "GND"))
        .pin(sig("3", "CS", "SD_CS")).pin(sig("4", "SCK", "SD_SCLK")).pin(sig("5", "MOSI", "SD_MOSI")).pin(sig("6", "MISO", "SD_MISO")));

    sch.add(Component::new("U2", "RTC_DS3231+AT24C32", HDR6, 210.0, 80.0)
        .pin(p_in("1", "VCC", "+3V3_IN")).pin(p_in("2", "GND", "GND"))
        .pin(sig("3", "SCL", "I2C_SCL")).pin(sig("4", "SDA", "I2C_SDA")));

    sch.add(Component::new("U3", "SHT30", HDR4, 210.0, 140.0)
        .pin(p_in("1", "VIN", "+3V3_SW")).pin(p_in("2", "GND", "GND"))
        .pin(sig("3", "SCL", "I2C_SCL")).pin(sig("4", "SDA", "I2C_SDA")));

    sch.add(Component::new("R1", "1k", R0805, 130.0, 140.0).pin(pas_l("1", "~", "LED_STAT")).pin(pas_r("2", "~", "LED_A")));
    sch.add(Component::new("D1", "LED", LED0805, 130.0, 180.0).pin(pas_l("1", "A", "LED_A")).pin(pas_r("2", "K", "GND")));

    sch.add(Component::new("SW1", "SW_SPDT", SW_SPDT, 60.0, 180.0)
    .pin(pas_l("2", "~", "BTN")).pin(pas_r("1", "~", "+3V3_SW")).pin(pas_r("3", "~", "GND")));

    sch.add(Component::new("C6", "100n", C0805, 60.0, 220.0).pin(pas_l("1", "~", "BTN")).pin(pas_r("2", "~", "GND")));

    for (r, x) in [("C1", 130.0), ("C2", 175.0), ("C3", 220.0), ("C4", 265.0), ("C5", 310.0)] {
        sch.add(Component::new(r, "100n", C0805, x, 250.0).pin(pas_l("1", "~", "+3V3_SW")).pin(pas_r("2", "~", "GND")));
    }
    sch.add(Component::new("C7", "10u", C0805, 20.0, 250.0).pin(pas_l("1", "~", "+3V3_IN")).pin(pas_r("2", "~", "GND")));

    // Divisor VBUS->ADC: vigila los 5V del USB (deteccion tiron de cable).
    // 5V -> R3(100k) -> nodo(VBUS_ADC) -> R4(100k) -> GND  => ~2.5V al ADC (GPIO5).
    sch.add(Component::new("R3", "100k", R0805, 90.0, 200.0)
        .pin(pas_l("1", "~", "VBUS")).pin(pas_r("2", "~", "VBUS_ADC")));
    sch.add(Component::new("R4", "100k", R0805, 90.0, 230.0)
        .pin(pas_l("1", "~", "VBUS_ADC")).pin(pas_r("2", "~", "GND")));



    let out = sch.render();
    std::fs::write("nks.kicad_sch", &out).expect("write .kicad_sch");

    let pro = format!(
        "{{\n  \"board\": {{ \"design_settings\": {{}} }},\n  \"meta\": {{ \"filename\": \"nks.kicad_pro\", \"version\": 1 }},\n  \"schematic\": {{}},\n  \"sheets\": [ [ \"{}\", \"Root\" ] ]\n}}\n",
        sch.root_uuid
    );
    std::fs::write("nks.kicad_pro", &pro).expect("write .kicad_pro");
    std::fs::write("nks.kicad_sym", sch.render_sym_lib()).expect("write .kicad_sym");
    std::fs::write("sym-lib-table", sch.render_sym_lib_table()).expect("write sym-lib-table");

    println!("wrote nks.kicad_sch ({} bytes) + project (stock footprints only)", out.len());
}

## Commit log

2026-07-23 feat(hw): placa NkS carrier — esquemático, layout rutado y documentación
    Placa portadora 80x90mm, 2 capas, para ESP32-S3 DevKitC-1 N16R8.
    - Esquemático con ERC limpio; huellas de librería estándar
    - Layout rutado, DRC 0 errores / 0 sin conectar
    - Plano de GND en ambas caras
    - 2x INMP441 (estéreo) + SHT30 + RTC + microSD
    - Gerbers verificados en fab/v1_2026-07
    [nks.kicad_pcb, nks.kicad_sch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]
2026-08-03 feat(sw1): interruptor SPDT (SS12D00) rutado y verificado DRC 0; elimina R2 pull-up; anade libreria de footprints propia nks.pretty
    [nks.kicad_pcb, nks.kicad_sch]
2026-08-03 feat(sw1): interruptor SPDT (SS12D00) rutado y verificado DRC 0; elimina R2 pull-up; anade libreria de footprints nks.pretty
2026-08-05 feat(gen): generador esquematico Rust nks-sch-gen con rediseño de alimentacion - SW1 SPDT, ENABLE (GPIO4), TPS22918 (rieles +3V3_IN/+3V3_SW), divisor VBUS
    [nks.kicad_sch]
2026-08-06 layout: reconstruccion PCB desde esquematico nuevo - 20 componentes colocados, DevKit orientado USB trasero, panel LED+switch frontal
    [nks.kicad_pcb, nks.kicad_sch]
2026-08-08 layout: planos GND ambas caras rellenados (58->38 sin conectar); recupera ficheros tras restauracion KiCad
    [nks.kicad_pcb, nks.kicad_sch]
2026-08-08 fix(micros): footprint A1/A2 corregido de 1x06 a 2x03 (INMP441 real) + mapeo pines 1=L/R,2=GND,3=WS,4=VDD,5=SCK,6=SD
    [nks.kicad_sch]
2026-08-08 Rutado completo de señales y alimentación (0 violaciones, pendiente costura GND)
    [nks.kicad_pcb]
2026-08-09 PCB completo: rutado de señales y alimentación terminado, 0 infracciones DRC (aviso de isla GND excluido)
    [nks.kicad_pcb]
2026-08-10 Serigrafia de montaje + texto identificativo. DRC 0/0/0 limpio.
    [nks.kicad_pcb]
2026-08-11 Serigrafia de montaje + texto identificativo NkS. DRC 0/0/0 limpio.
    [nks.kicad_pcb, nks.kicad_sch]
